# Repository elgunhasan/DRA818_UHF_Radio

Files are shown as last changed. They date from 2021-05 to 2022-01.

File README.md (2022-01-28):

# DRA818_UHF_Radio
http://599.cz/view.php?cisloclanku=2020010801

Firmware in Atmega328PB (Atmega328P)

I created the firmware using a MCS-Basom-AVR editor/compiler version 2.0.8.1 (some kind of a Basic-like language). I can't guarantee that it is error free. It runs on the 8 MHz frequency of internal RC oscillator. So, when programming, it is necessary to turn off the frequency division of eight in the configuration bits. I also recommend setting Brown-Out to 2.7 Volts (reset when supply voltage drops). I saved compiled hex and bin code for both Atmega types into the DOWNLOAD section of this web-page. I plan to save the source code there, but later, after I comment it in a comprehensible way.

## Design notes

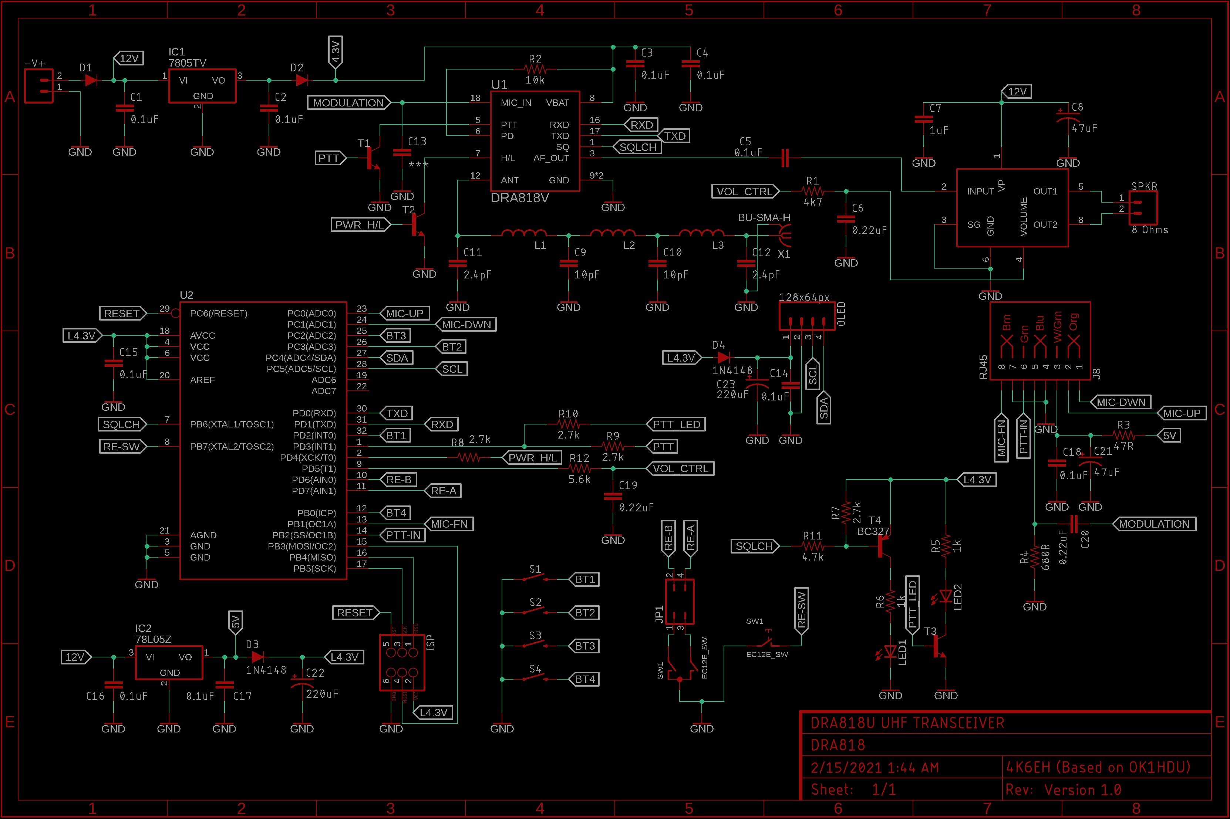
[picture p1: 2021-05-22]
DRA818/DRA818/schematic.png

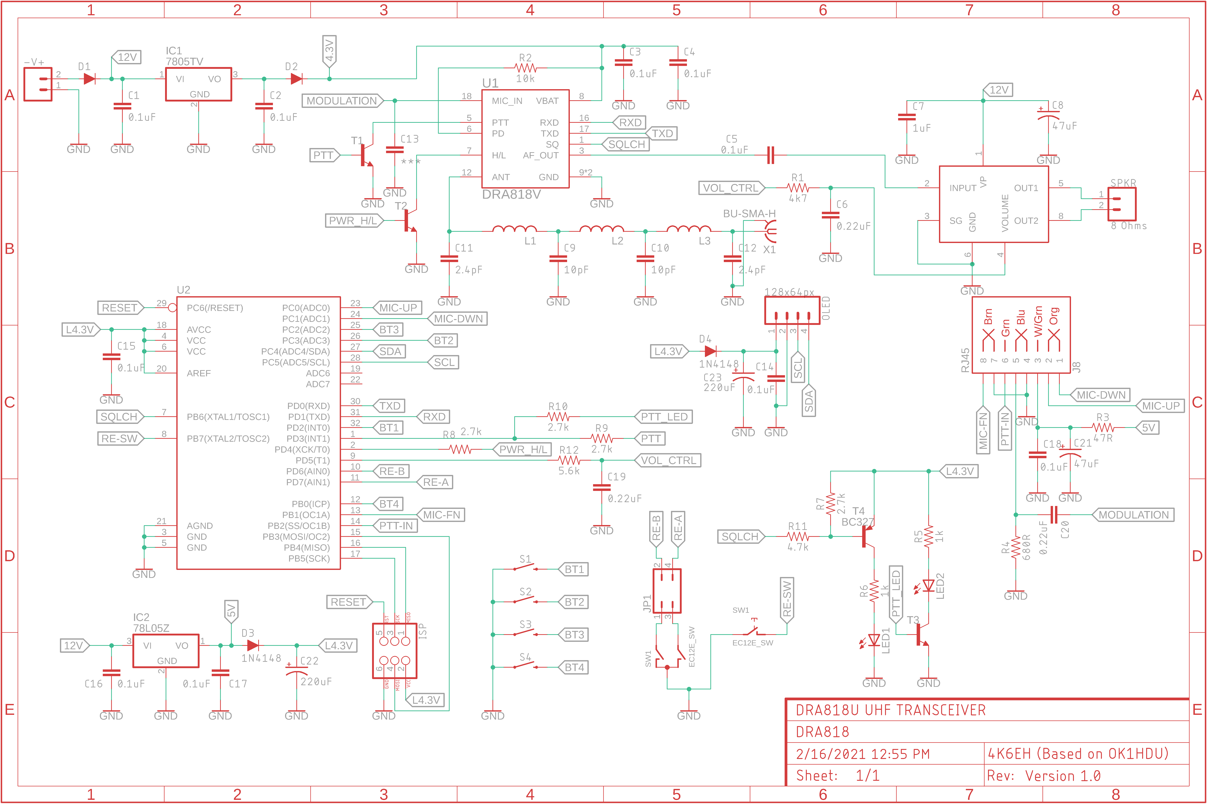
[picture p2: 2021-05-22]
DRA818/DRA818/dra818u.png

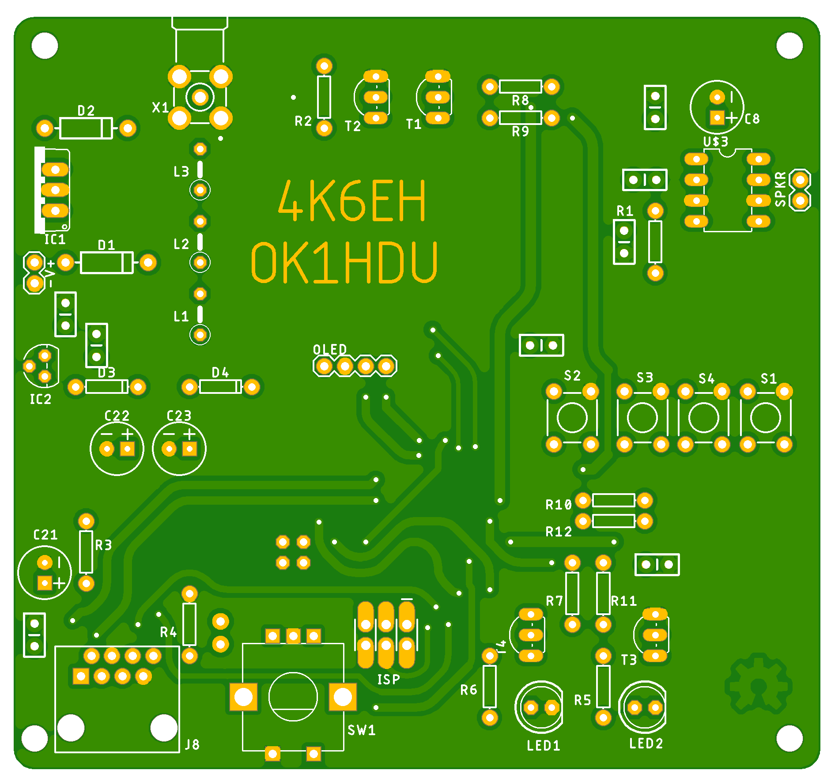
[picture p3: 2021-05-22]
DRA818/DRA818/DRA818_Top.png

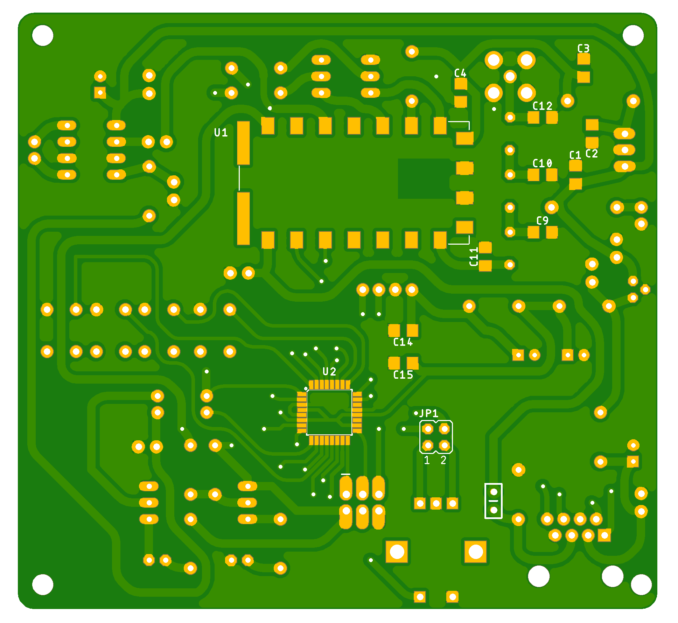
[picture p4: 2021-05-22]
DRA818/DRA818/DRA818_Bottom.png

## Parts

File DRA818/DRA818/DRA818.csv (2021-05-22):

Part | Value | Package | Description | AVAILABILITY | DESCRIPTION | MF | MP | MPN | OC_FARNELL | OC_NEWARK | PACKAGE | POPULARITY | PRICE | PROD_ID | SF_ID | SF_SKU | SPICEPREFIX | VALUE
-V+ |  | 1X02 | Multi connection point. Often used as Generic Header-pin footprint for 0.1 inch spaced/style header connections
C1 | 0.1uF | 1206 | 1µF ceramic capacitors |  |  |  |  |  |  |  |  |  |  | CAP-09822 |  |  |  | 1.0uF
C2 | 0.1uF | 1206 | 1µF ceramic capacitors |  |  |  |  |  |  |  |  |  |  | CAP-09822 |  |  |  | 1.0uF
C3 | 0.1uF | 1206 | 1µF ceramic capacitors |  |  |  |  |  |  |  |  |  |  | CAP-09822 |  |  |  | 1.0uF
C4 | 0.1uF | 1206 | 1µF ceramic capacitors |  |  |  |  |  |  |  |  |  |  | CAP-09822 |  |  |  | 1.0uF
�e4 | 0.1uF | CAP-PTH-SMALL-KIT | 0.1µF ceramic capacitors |  |  |  |  |  |  |  |  |  |  | CAP-08370 |  |  |  | 0.1uF
C6 | 0.22uF | CAP-PTH-SMALL-KIT | 0.1µF ceramic capacitors |  |  |  |  |  |  |  |  |  |  | CAP-08370 |  |  |  | 0.1uF
C7 | 1uF | CAP-PTH-SMALL-KIT | 0.1µF ceramic capacitors |  |  |  |  |  |  |  |  |  |  | CAP-08370 |  |  |  | 0.1uF
C8 | 47uF | CPOL-RADIAL-2.5MM-6.5MM | 100µF polarized capacitors |  |  |  |  |  |  |  |  |  |  | CAP-08439 |  |  |  | 100uF
C9 | 10pF | 1206 | 1µF ceramic capacitors |  |  |  |  |  |  |  |  |  |  | CAP-09822 |  |  |  | 1.0uF
C10 | 10pF | 1206 | 1µF ceramic capacitors |  |  |  |  |  |  |  |  |  |  | CAP-09822 |  |  |  | 1.0uF
C11 | 2.4pF | 1206 | 1µF ceramic capacitors |  |  |  |  |  |  |  |  |  |  | CAP-09822 |  |  |  | 1.0uF
C12 | 2.4pF | 1206 | 1µF ceramic capacitors |  |  |  |  |  |  |  |  |  |  | CAP-09822 |  |  |  | 1.0uF
C13 | *** | CAP-PTH-SMALL-KIT | 0.1µF ceramic capacitors |  |  |  |  |  |  |  |  |  |  | CAP-08370 |  |  |  | 0.1uF
C14 | 0.1uF | 1206 | 1µF ceramic capacitors |  |  |  |  |  |  |  |  |  |  | CAP-09822 |  |  |  | 1.0uF
C15 | 0.1uF | 1206 | 1µF ceramic capacitors |  |  |  |  |  |  |  |  |  |  | CAP-09822 |  |  |  | 1.0uF
C16 | 0.1uF | CAP-PTH-SMALL-KIT | 0.1µF ceramic capacitors |  |  |  |  |  |  |  |  |  |  | CAP-08370 |  |  |  | 0.1uF
C17 | 0.1uF | CAP-PTH-SMALL-KIT | 0.1µF ceramic capacitors |  |  |  |  |  |  |  |  |  |  | CAP-08370 |  |  |  | 0.1uF
C18 | 0.1uF | CAP-PTH-SMALL-KIT | 0.1µF ceramic capacitors |  |  |  |  |  |  |  |  |  |  | CAP-08370 |  |  |  | 0.1uF
C19 | 0.22uF | CAP-PTH-SMALL-KIT | 0.1µF ceramic capacitors |  |  |  |  |  |  |  |  |  |  | CAP-08370 |  |  |  | 0.1uF
C20 | 0.22uF | CAP-PTH-SMALL-KIT | 0.1µF ceramic capacitors |  |  |  |  |  |  |  |  |  |  | CAP-08370 |  |  |  | 0.1uF
C21 | 47uF | CPOL-RADIAL-2.5MM-6.5MM | 100µF polarized capacitors |  |  |  |  |  |  |  |  |  |  | CAP-08439 |  |  |  | 100uF
C22 | 220uF | CPOL-RADIAL-2.5MM-6.5MM | 100µF polarized capacitors |  |  |  |  |  |  |  |  |  |  | CAP-08439 |  |  |  | 100uF
C23 | 220uF | CPOL-RADIAL-2.5MM-6.5MM | 100µF polarized capacitors |  |  |  |  |  |  |  |  |  |  | CAP-08439 |  |  |  | 100uF
D1 |  | DIODE-1N4001 | Diode |  |  |  |  |  |  |  |  |  |  | DIO-09176 |  |  |  | 1A/50V/1.1V
D2 |  | DIODE-1N4001 | Diode |  |  |  |  |  |  |  |  |  |  | DIO-09176 |  |  |  | 1A/50V/1.1V
D3 | 1N4148 | DIODE-1N4148 | Diode |  |  |  |  |  |  |  |  |  |  | DIO-08378 |  |  |  | 200mA/100V/1V
D4 | 1N4148 | DIODE-1N4148 | Diode |  |  |  |  |  |  |  |  |  |  | DIO-08378 |  |  |  | 200mA/100V/1V
IC1 | 7805TV | TO220V | Positive VOLTAGE REGULATOR |  |  |  |  |  |  |  |  | 57
IC2 | 78L05Z | TO92 | Positive VOLTAGE REGULATOR |  |  |  |  |  |  |  |  | 12
ISP |  | 2X3_OFFSET | AVR ISP 6 Pin
J8 | RJ45 | RJ45-8 | RJ45 Jack - 8 pin |  |  |  |  |  |  |  |  |  |  | CONN-08506 | PRT-00643 |  |  | RJ45
JP1 |  | JP2Q | JUMPER |  |  |  |  |  |  |  |  | 2
L1 |  | 0207/5V | INDUCTOR, American symbol |  |  |  |  |  |  |  |  | 0 |  |  |  |  | L
L2 |  | 0207/5V | INDUCTOR, American symbol |  |  |  |  |  |  |  |  | 0 |  |  |  |  | L
L3 |  | 0207/5V | INDUCTOR, American symbol |  |  |  |  |  |  |  |  | 0 |  |  |  |  | L
LED1 |  | LED5MM | LED
LED2 |  | LED5MM | LED
OLED | 128x64px | 1X04 | Multi connection point. Often used as Generic Header-pin footprint for 0.1 inch spaced/style header connections |  |  |  |  |  |  |  |  |  |  | CONN-09696
R1 | 4k7 | AXIAL-0.3 | Generic Resistor Package
R2 | 10k | AXIAL-0.3 | Generic Resistor Package
R3 | 47R | AXIAL-0.3 | Generic Resistor Package
R4 | 680R | AXIAL-0.3 | Generic Resistor Package
R5 | 1k | AXIAL-0.3 | Generic Resistor Package
R6 | 1k | AXIAL-0.3 | Generic Resistor Package
R7 | 2.7k | AXIAL-0.3 | Generic Resistor Package
R8 | 2.7k | AXIAL-0.3 | Generic Resistor Package
R9 | 2.7k | AXIAL-0.3 | Generic Resistor Package
R10 | 2.7k | AXIAL-0.3 | Generic Resistor Package
R11 | 4.7k | AXIAL-0.3 | Generic Resistor Package
R12 | 5.6k | AXIAL-0.3 | Generic Resistor Package
S1 |  | TACTILE_SWITCH_PTH_6.0MM | Momentary Switch (Pushbutton) - SPST |  |  |  |  |  |  |  |  |  |  | SWCH-08441 |  | COM-00097
S2 |  | TACTILE_SWITCH_PTH_6.0MM | Momentary Switch (Pushbutton) - SPST |  |  |  |  |  |  |  |  |  |  | SWCH-08441 |  | COM-00097
S3 |  | TACTILE_SWITCH_PTH_6.0MM | Momentary Switch (Pushbutton) - SPST |  |  |  |  |  |  |  |  |  |  | SWCH-08441 |  | COM-00097
S4 |  | TACTILE_SWITCH_PTH_6.0MM | Momentary Switch (Pushbutton) - SPST |  |  |  |  |  |  |  |  |  |  | SWCH-08441 |  | COM-00097
SPKR | 8 Ohms | 1X02 | Multi connection point. Often used as Generic Header-pin footprint for 0.1 inch spaced/style header connections
SW1 | EC12E_SW | ALPS_EC12E_SW | ALPS rotary Encoder EC12E series with switch |  |  |  |  | EC12E2424407 | 1520813 | 74M1068 |  | 3
T1 |  | TO92-CBE | NPN Transistror |  |  |  |  |  |  |  |  | 0
T2 |  | TO92-CBE | NPN Transistror |  |  |  |  |  |  |  |  | 0
T3 |  | TO92-CBE | NPN Transistror |  |  |  |  |  |  |  |  | 0
T4 | BC327 | TO92-EBC | PNP Transistror |  |  |  |  |  |  |  |  | 1
U$1 | TDA7052A | DIL08 | 1W Mono audio amplifier Check prices | Bad | Amplifier IC 1-Channel (Mono) Class AB 8-DIP | NXP USA | TDA7052A/N2,112 |  |  |  | DIP-8 NXP Semiconductors |  | None
U1 | DRA818V | DORJI_DRA818V | VHF Band Voice Transceiver Module | Unavailable |  | DORJI | DRA818V |  |  |  | Package |  | None
U2 |  | TQFP32-08 | Popular 328P in QFP |  |  |  |  |  |  |  |  |  |  | IC-09069 |  |  |  | ATMEGA328P_TQFP
X1 | BU-SMA-H | BU-SMA-H | FEMALE SMA CONNECTOR |  |  |  |  |  | unknown | unknown |  | 4

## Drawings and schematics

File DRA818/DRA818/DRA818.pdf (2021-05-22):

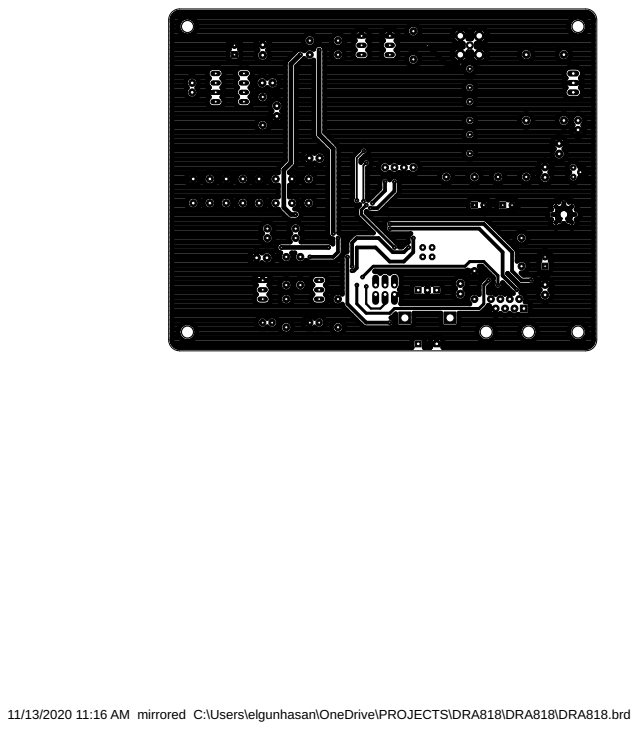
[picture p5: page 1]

11/13/2020 11:16 AM mirrored C:\Users\elgunhasan\OneDrive\PROJECTS\DRA818\DRA818\DRA818.brd

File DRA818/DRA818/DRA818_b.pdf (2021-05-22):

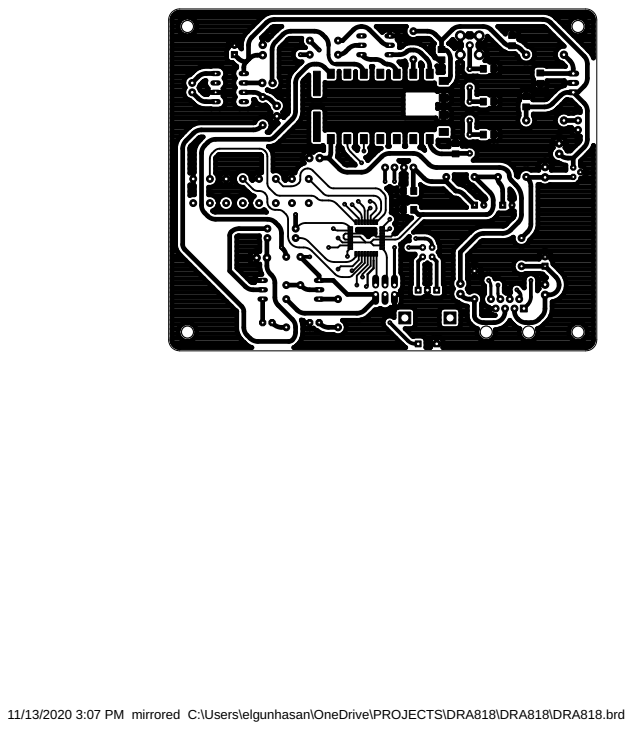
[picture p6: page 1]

11/13/2020 3:07 PM mirrored C:\Users\elgunhasan\OneDrive\PROJECTS\DRA818\DRA818\DRA818.brd

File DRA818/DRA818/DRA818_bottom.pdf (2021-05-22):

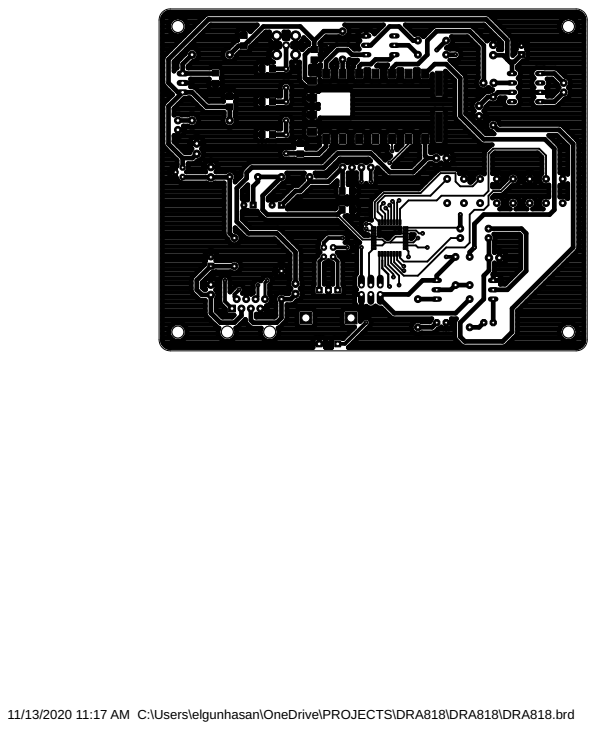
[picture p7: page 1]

11/13/2020 11:17 AM C:\Users\elgunhasan\OneDrive\PROJECTS\DRA818\DRA818\DRA818.brd

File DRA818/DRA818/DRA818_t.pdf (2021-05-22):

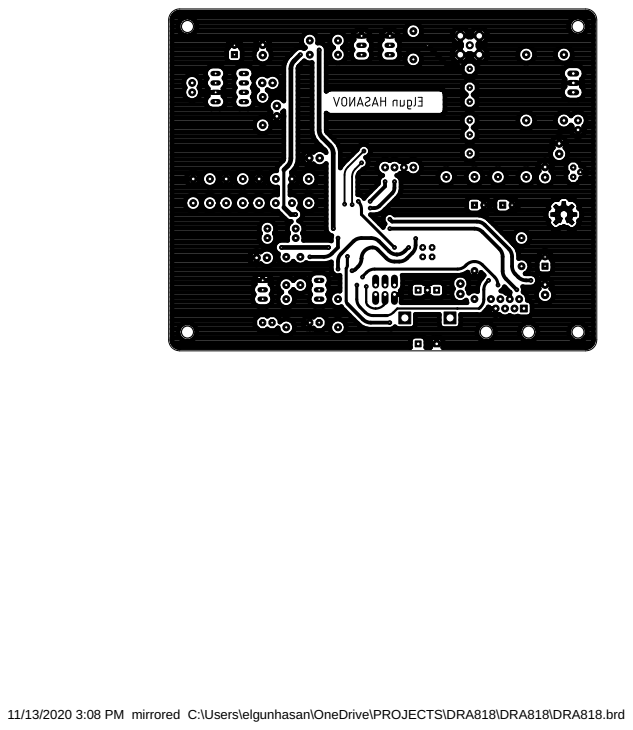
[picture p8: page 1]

11/13/2020 3:08 PM mirrored C:\Users\elgunhasan\OneDrive\PROJECTS\DRA818\DRA818\DRA818.brd

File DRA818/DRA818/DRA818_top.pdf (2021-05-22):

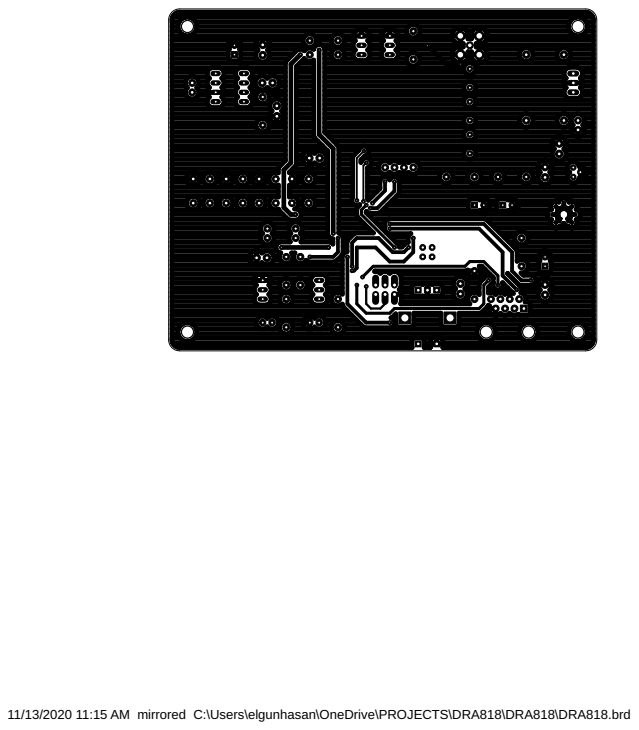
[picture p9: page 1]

11/13/2020 11:15 AM mirrored C:\Users\elgunhasan\OneDrive\PROJECTS\DRA818\DRA818\DRA818.brd

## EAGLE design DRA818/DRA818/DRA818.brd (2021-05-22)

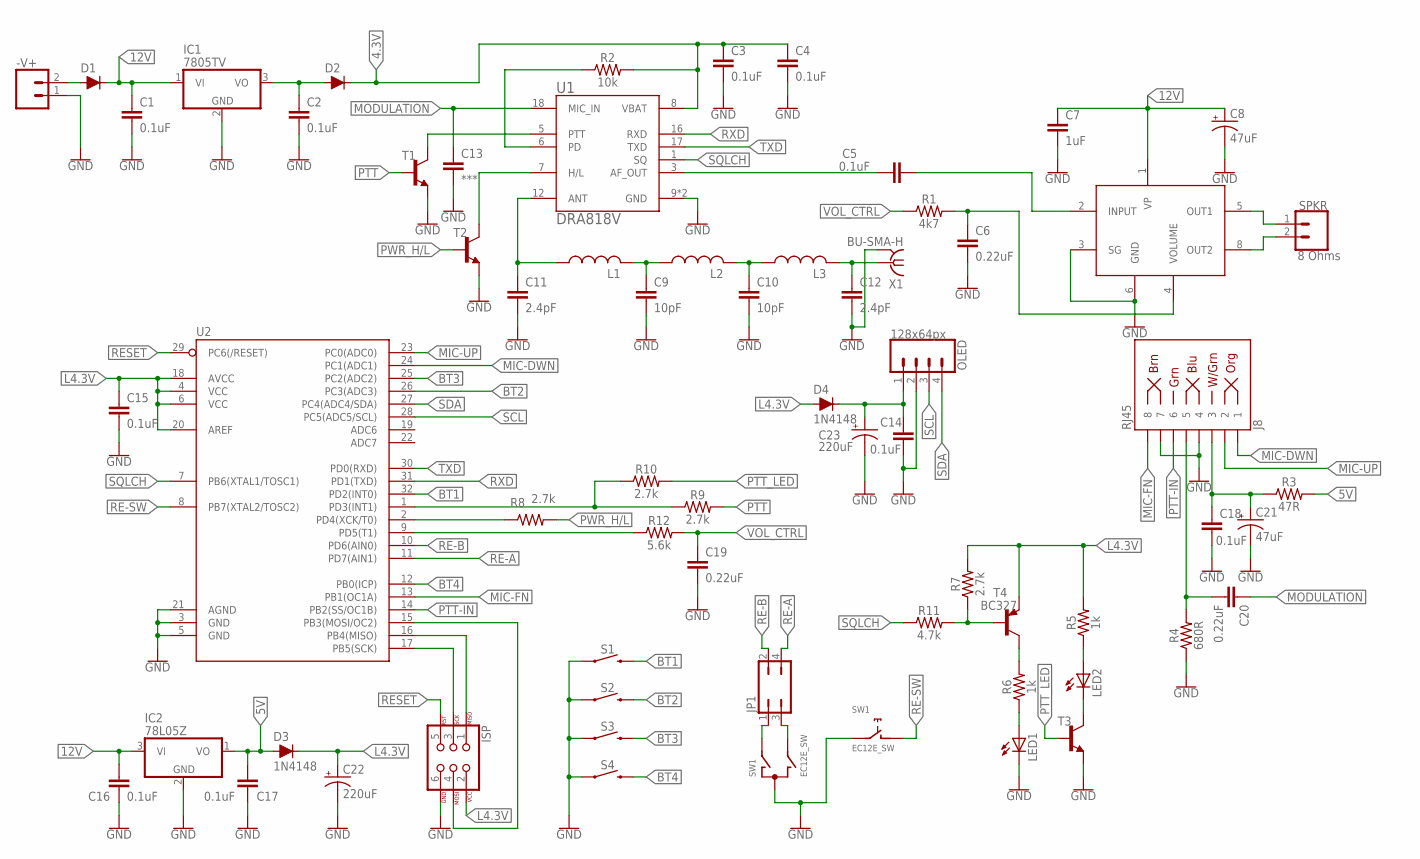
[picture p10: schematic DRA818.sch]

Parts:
-V+: CONN_02; 1X02
C1, C2, C3, C4, C14, C15: 0.1uF; 1206
C5, C16, C17, C18: 0.1uF; CAP-PTH-SMALL-KIT
C6, C19, C20: 0.22uF; CAP-PTH-SMALL-KIT
C7: 1uF; CAP-PTH-SMALL-KIT
C8, C21: 47uF; CPOL-RADIAL-2.5MM-6.5MM
C9, C10: 10pF; 1206
C11, C12: 2.4pF; 1206
C13: ***; CAP-PTH-SMALL-KIT
C22, C23: 220uF; CPOL-RADIAL-2.5MM-6.5MM
D1, D2: DIODE-PTH; DIODE-1N4001
D3, D4: 1N4148; DIODE-1N4148
IC1: 7805TV; TO220V
IC2: 78L05Z; TO92
ISP: AVR_SPI_PROG_3X2OFFSET_PADS; 2X3_OFFSET
J8: RJ45; RJ45-8
JP1: JP2Q
L1, L2, L3: L-US0207/5V; 0207/5V
LED1, LED2: LED5MM
OLED: 128x64px; 1X04
R1: 4k7; AXIAL-0.3
R2: 10k; AXIAL-0.3
R3: 47R; AXIAL-0.3
R4: 680R; AXIAL-0.3
R5, R6: 1k; AXIAL-0.3
R7, R8, R9, R10: 2.7k; AXIAL-0.3
R11: 4.7k; AXIAL-0.3
R12: 5.6k; AXIAL-0.3
S1, S2, S3, S4: MOMENTARY-SWITCH-SPST-PTH-6.0MM; TACTILE_SWITCH_PTH_6.0MM
SPKR: 8 Ohms; 1X02
SW1: EC12E_SW; ALPS_EC12E_SW
T1, T2, T3: BC337-25-NPN-TO92-CBE; TO92-CBE
T4: BC327; TO92-EBC
U1: DRA818V; DORJI_DRA818V
U2: ATMEGA328P_TQFP; TQFP32-08
U$3: TDA7052B; DIL08
X1: BU-SMA-H

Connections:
4.3V: C3.1, C4.1, D2.C, R2.P$2 (2), U1.8 (VBAT)
5V: C17.1, D3.A, IC2.1 (VO), R3.P$2 (2)
12V: C1.1, C7.1, C8.1 (+), C16.2, D1.C, IC1.1 (VI), IC2.3 (VI), U$3.1 (VP)
BT1: S1.3 (2), U2.32 (PD2(INT0))
BT2: S2.3 (2), U2.26 (PC3(ADC3))
BT3: S3.3 (2), U2.25 (PC2(ADC2))
BT4: S4.3 (2), U2.12 (PB0(ICP))
GND: -V+.1, C1.2, C2.2, C3.2, C4.2, C6.2, C7.2, C8.2 (-), C9.2, C10.2, C11.2, C12.2, C13.2, C14.2, C15.2, C16.1, C17.2, C18.1, C19.2, C21.2 (-), C22.2 (-), C23.2 (-), IC1.2 (GND), IC2.2 (GND), ISP.6, J8.4, J8.7, LED1.K (C), OLED.2, R4.P$1 (1), S1.1, S2.1, S3.1, S4.1, SW1.C, SW1.E (2), T1.E, T2.E, T3.E, U1.9 (GND), U1.10 (GND), U2.3 (GND), U2.5 (GND), U2.21 (AGND), U$3.3 (SG), U$3.6 (GND), X1.2, X1.3 (2), X1.4 (2), X1.5 (2)
L4.3V: C15.1, C22.1 (+), D3.C, D4.A, ISP.2, R5.P$2 (2), R7.P$2 (2), T4.E, U2.4 (VCC), U2.6 (VCC), U2.18 (AVCC), U2.20 (AREF)
MIC-DWN: J8.1, U2.24 (PC1(ADC1))
MIC-FN: J8.8, U2.13 (PB1(OC1A))
MIC-UP: J8.2, U2.23 (PC0(ADC0))
MODULATION: C13.1, C20.1, U1.18 (MIC_IN)
unnamed: -V+.2, D1.A
unnamed: R2.P$1 (1), U1.6 (PD)
unnamed: C2.1, D2.A, IC1.3 (VO)
unnamed: T1.C, U1.5 (PTT)
unnamed: T2.C, U1.7 (H/L)
unnamed: C11.1, L1.1, U1.12 (ANT)
unnamed: C9.1, L1.2, L2.1
unnamed: C10.1, L2.2, L3.1
unnamed: C12.1, L3.2, X1.1
unnamed: C5.1, U1.3 (AF_OUT)
unnamed: C5.2, U$3.2 (INPUT)
unnamed: SPKR.1, U$3.5 (OUT1)
unnamed: SPKR.2, U$3.8 (OUT2)
unnamed: ISP.4, U2.15 (PB3(MOSI/OC2))
unnamed: ISP.1, U2.16 (PB4(MISO))
unnamed: ISP.3, U2.17 (PB5(SCK))
unnamed: R9.P$1 (1), R10.P$1 (1), U2.1 (PD3(INT1))
unnamed: R8.P$1 (1), U2.2 (PD4(XCK/T0))
unnamed: R12.P$1 (1), U2.9 (PD5(T1))
unnamed: JP1.3, SW1.B
unnamed: JP1.1, SW1.A
unnamed: R6.P$2 (2), T4.C
unnamed: LED1.A, R6.P$1 (1)
unnamed: LED2.A, R5.P$1 (1)
unnamed: LED2.K (C), T3.C
unnamed: C14.1, C23.1 (+), D4.C, OLED.1
unnamed: C20.2, J8.5, R4.P$2 (2)
unnamed: R7.P$1 (1), R11.P$2 (2), T4.B
unnamed: C18.2, C21.1 (+), J8.3, R3.P$1 (1)
unnamed: C6.1, R1.P$2 (2), U$3.4 (VOLUME)
PTT: R9.P$2 (2), T1.B
PTT-IN: J8.6, U2.14 (PB2(SS/OC1B))
PTT_LED: R10.P$2 (2), T3.B
PWR_H/L: R8.P$2 (2), T2.B
RE-A: JP1.4, U2.11 (PD7(AIN1))
RE-B: JP1.2, U2.10 (PD6(AIN0))
RE-SW: SW1.D (1), U2.8 (PB7(XTAL2/TOSC2))
RESET: ISP.5, U2.29 (PC6(/RESET))
RXD: U1.16 (RXD), U2.31 (PD1(TXD))
SCL: OLED.3, U2.28 (PC5(ADC5/SCL))
SDA: OLED.4, U2.27 (PC4(ADC4/SDA))
SQLCH: R11.P$1 (1), U1.1 (SQ), U2.7 (PB6(XTAL1/TOSC1))
TXD: U1.17 (TXD), U2.30 (PD0(RXD))
VOL_CTRL: C19.1, R1.P$1 (1), R12.P$2 (2)

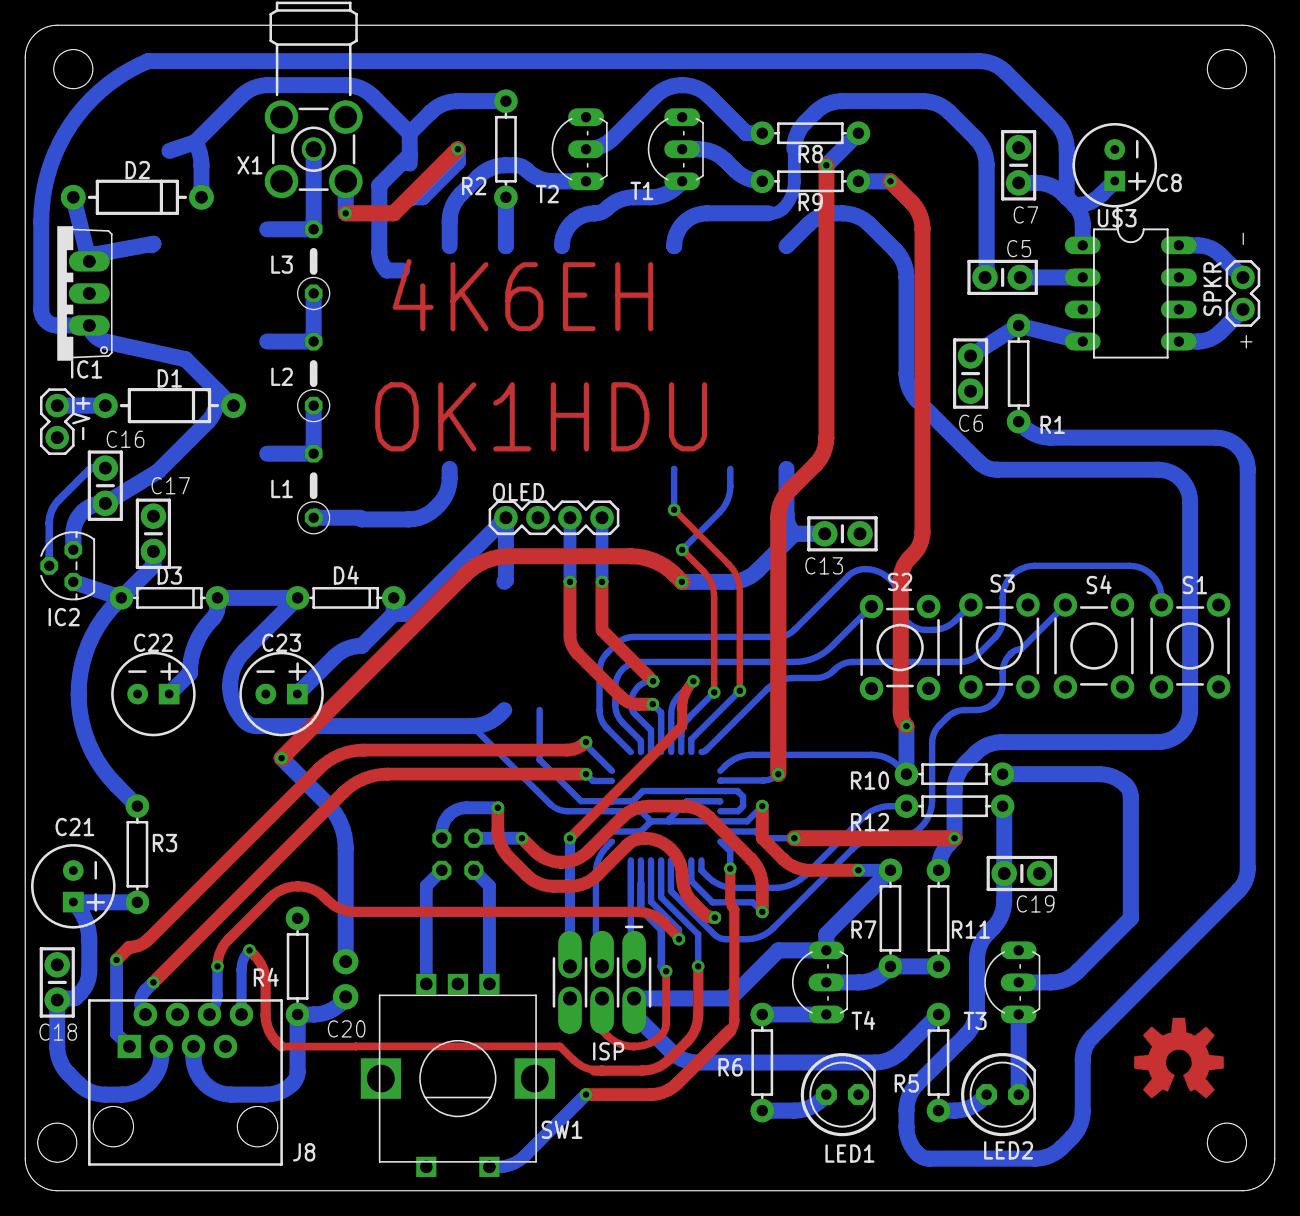
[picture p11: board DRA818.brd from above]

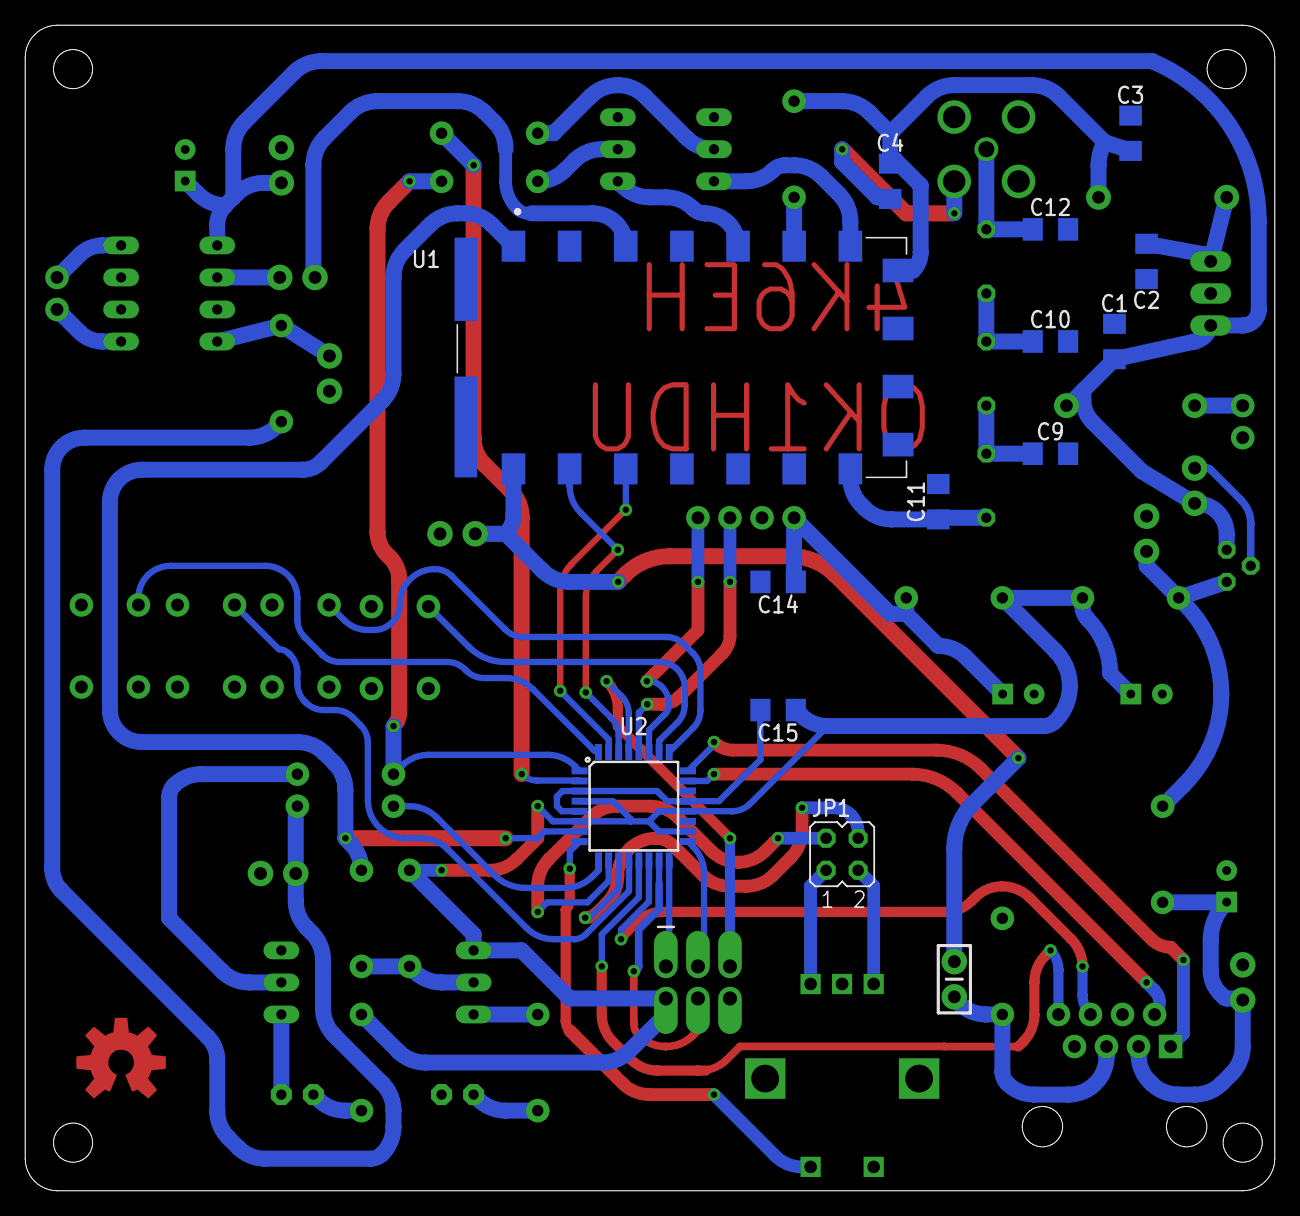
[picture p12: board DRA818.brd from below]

Board: 2 copper layers, 99.0 x 92.4 mm, 66 parts (14 on the bottom side), 57 nets.

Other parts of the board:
U$2: OSHW-LOGO-L_COPPER

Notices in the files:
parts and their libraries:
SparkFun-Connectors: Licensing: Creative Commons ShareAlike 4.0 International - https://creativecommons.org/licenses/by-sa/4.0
